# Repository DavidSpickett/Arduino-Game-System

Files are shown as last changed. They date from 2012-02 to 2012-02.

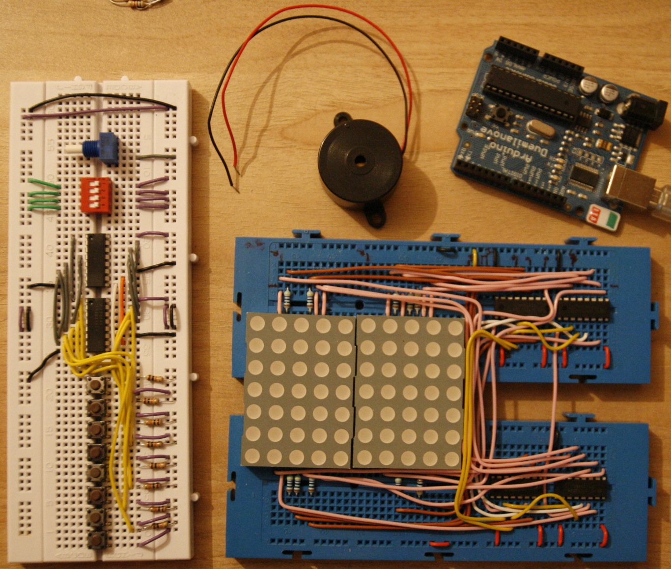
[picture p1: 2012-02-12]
Prototype hardware.JPG

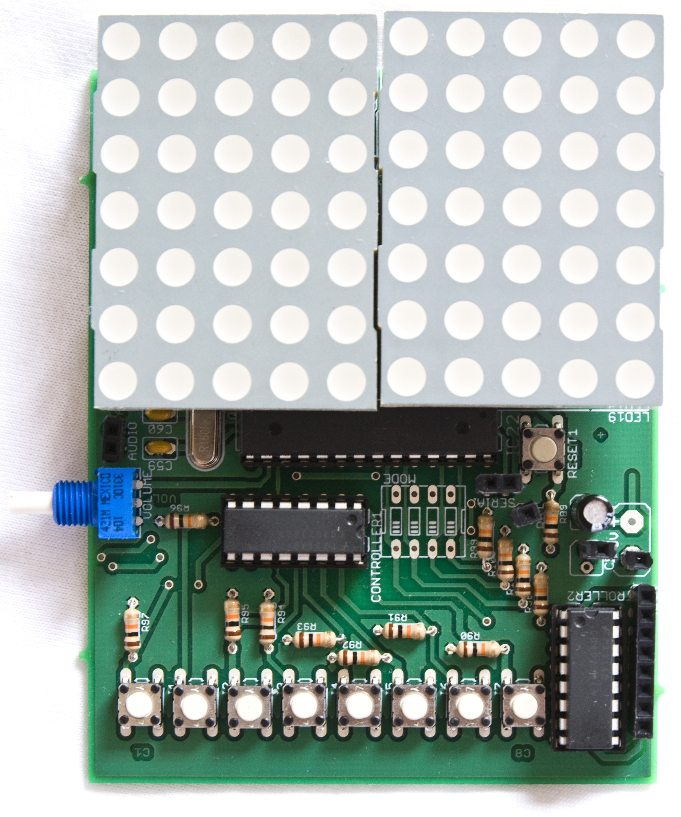
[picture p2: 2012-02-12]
Final board.jpg

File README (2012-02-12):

This is my second year design project. The module was based around the Arduino system and I chose to build a simple hand held game system using L.E.D. grids as displays.

Final report - full documentation of the project
parts.txt - parts list as exported from Eagle
Eagle Files - board layout and schematic created in Eagle
pong_PCB - the final demo application for the device, plays one or two player pong at a set speed.
scoll_text_PCB - a demo which scrolls a long piece of text across the displays.
Final board - a picture of the final assembled device
Final PCB - the final board layout
Final schematic - the final schematic for the system
Programming - the board begin programmed using an empty Arduino
Prototype hardware - the initial hardware for the system
Data Sheets - data sheets for the main components used

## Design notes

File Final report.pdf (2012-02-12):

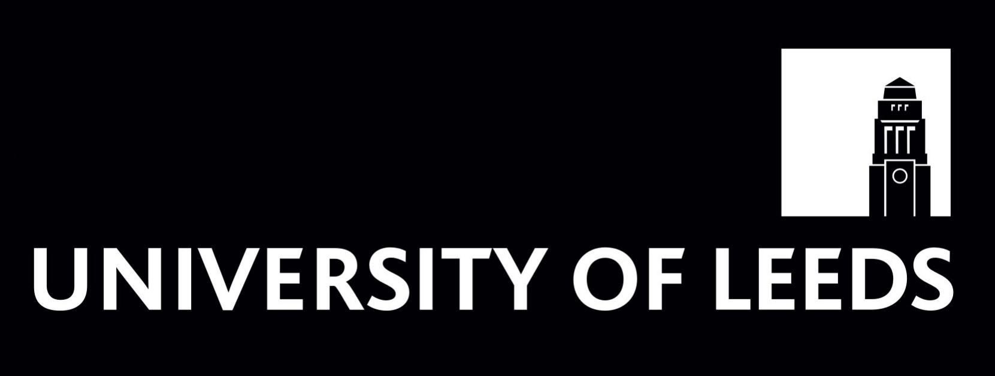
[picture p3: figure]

# Arduino-based games system

# David Spickett

MEng in Electronic and Electrical Engineering

ELEC2645 Embedded Systems Project

## School of Electronic and Electrical Engineering

FACULTY OF ENGINEERING

Session | 2010 / 2011
Student ID | 200483181

Contents

Abstract! | ! | ! | ! | ! | ! | ! | ! | ! | ! | 1
Introduction !! | ! | ! | ! | ! | ! | ! | ! | ! | 1
Software Overview!! | ! | ! | ! | ! | ! | ! | ! | 2
Hardware Overview!! | ! | ! | ! | ! | ! | ! | ! | 4
Testing!! | ! | ! | ! | ! | ! | ! | ! | ! | ! | 8
Conclusion!! | ! | ! | ! | ! | ! | ! | ! | ! | 9
References!! | ! | ! | ! | ! | ! | ! | ! | ! | 9

Arduino-based games system

Abstract

The following document details the design and construction of an Arduino based games system. It includes a display, buttons, external inputs and a speaker connection. It is designed to be reprogrammable and allow users to easily write applications making use of the hardware.

Introduction

The aim of this project was to make a platform to allow users to easily write and quickly iterate Arduino programs that make use of a display. Particularly interactive programs such as games. The system includes and L.E.D. display, input buttons, external inputs and audio output. The final goal is to have the system be much like a development board one might supply to developers prior to the production of a system, abstracting all the hardware access into simple code.

Software Overview

The software for the system is written as a template file which programs are built on. The flowchart below is for a generic program.

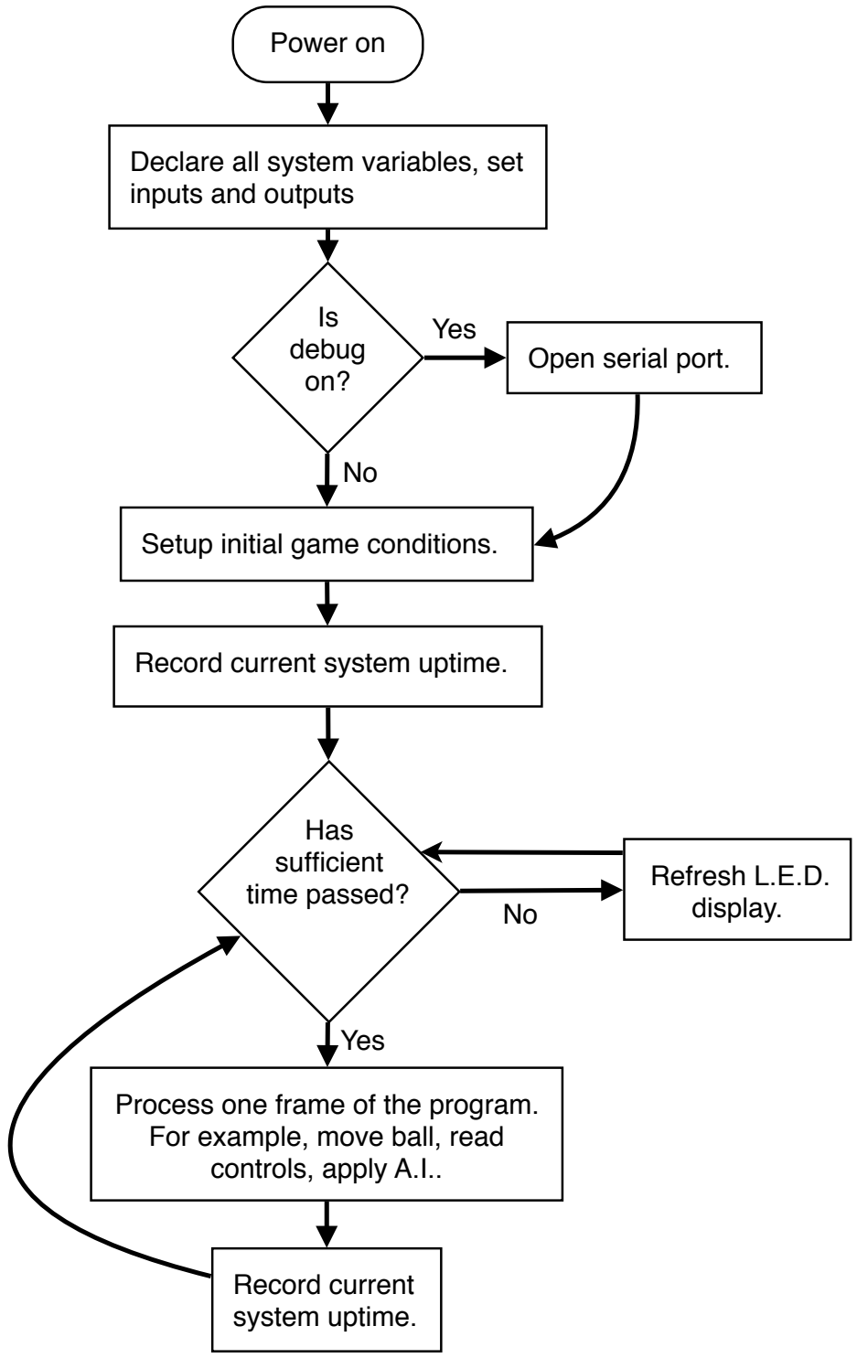
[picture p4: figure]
Power on; Declare all system variables, set inputs and outputs; Is debug; Open serial port.; Yes; Setup initial game conditions.; Record current system uptime.; Has sufficient; time passed?; Refresh L.E.D.; display.; Process one frame of the program. For example, move ball, read controls, apply A.I..

The template has all of the pin numbers built into it by making use of #define statements. For example:
#define speakerPin 10

Using defines reduces program size, makes the built in functions easier to understand and the system configurable.

screenArray -
- a 10x7 array of bytes, which holds all the pixels which make up the screen.
- this is only ever accessed by the system itself.

modeSwitch -
- a byte which holds the current state of the mode switch.
- can be read by calling “readModeSwitch”.

controllerOne & controllerTwo -
- (each one is) a byte which holds the states of the inputs.
- is updated by calling readControllerOne/Two and then queried using readControllerOne/ TwoButton(button).

dataValues -
- this is only ever used by the system and is an array of bytes, each being a power of 2.
- it is used to speed up other system functions by being a lookup table where the code would normally do a calculation.

time -
- an unsigned long which is used to hold the current system uptime in milliseconds.
- this is used to time when the loop of a given program will run, allowing the screen to be refreshed at all other times.

Finally there are functions built in to handle reading and writing to the various pieces of hardware.

setPixel(x,y) -
- turns on the pixel at x,y on the screen.

clearPixel(x,y) -
- as setPixel except the pixel at x,y is turned off.

readPixel(x,y) -
- returns the state of the pixel at x,y.

clearScreen() -
- turns off all pixels.

readControllerOne() -
- reads the built in buttons and store result in controllerOne.

readControllerTwo() -
- as for readControllerOne().

readControllerOneButton(button) -
- reads a given button and returns true if it is held down, false otherwise.

- this makes use of binary logic to do this. The value of the port is anded with the value of the button (in powers of 2), to isolate that bit and if the result is equal to the value of the button then it returns true.

readControllerTwoButton(button) -
- as for readControllerOneButton(button).

playTone(frequency,duration) -
- plays a given frequency for a given time through the speaker output.

updateScreen() -
- this takes the current screenArray and applies it to the actual L.E.D. grids.
- it does this by scanning across both grids simultaneously, setting the same column on each one. Setting a row low turns on the L.E.D. in the current row and column.

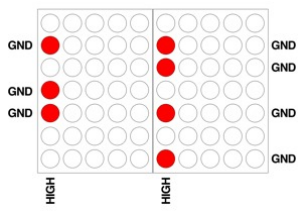
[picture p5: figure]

This function calculates values based on each column of screenArray and outputs these using code based upon the Arduinoʼs built in shiftOut function.

shiftIn(dataPin) -
- this is based on source code from the Arduino shiftIn tutorials, with optmisations for this setup.

readModeSwitch() -
- this reads the value of the mode switch into “modeSwitch”.

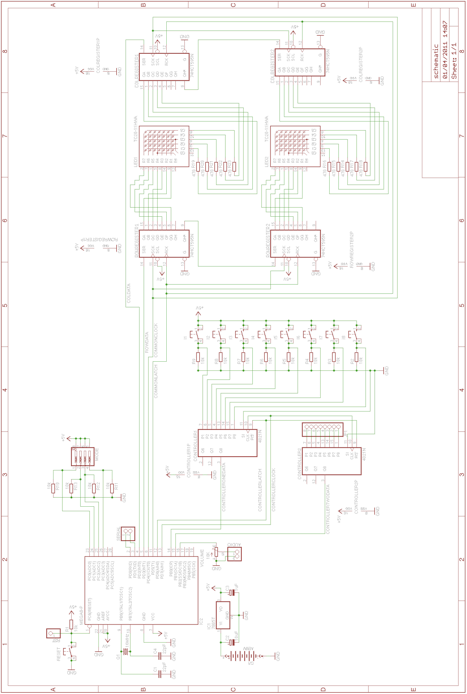
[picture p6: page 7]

Hardware Overview

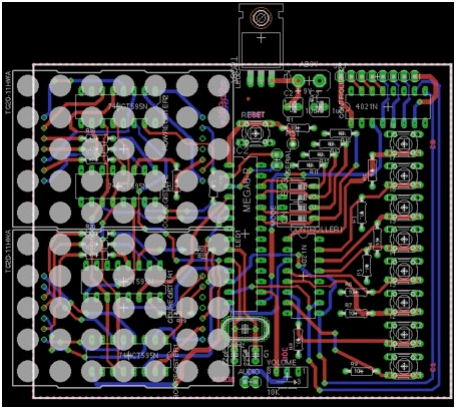
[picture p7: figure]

Part | Value | Device | Package | Library
AUDIO | n/a | PINHD-1X2 | 1X02 | pinhead
C1 | 22pF | C2, 5-3 | C2.5-3 | capacitor-wima
C2 | 10uF | CPOL-EUB45181A | B45181A | resistor
C3 | 1uF | CPOL-EUB45181A | B45181A | resistor
C4 | 22pF | C2, 5-3 | C2.5-3 | capacitor-wima
COLREGISTE R1 | 74HCT595N | 74HCT595N | DIL16 | 74xx-eu
COLREGISTE R2 | 74HCT595N | 74HCT595N | DIL16 | 74xx-eu
CONTROLLER 1 | 4021N | 4021N | DIL16 | 40xx

Part | Value | Device | Package | Library
CONTROLLER 2 | 4021N | 4021N | DIL16 | 40xx
G1 | AB9V | AB9V | AB9V | battery
I1 | n/a | 10-XX | B3F-10XX | switch-omron
I2 | n/a | 10-XX | B3F-10XX | switch-omron
I3 | n/a | 10-XX | B3F-10XX | switch-omron
I4 | n/a | 10-XX | B3F-10XX | switch-omron
I5 | n/a | 10-XX | B3F-10XX | switch-omron
I6 | n/a | 10-XX | B3F-10XX | switch-omron
I7 | n/a | 10-XX | B3F-10XX | switch-omron
I8 | n/a | 10-XX | B3F-10XX | switch-omron
IC1 | 7805T | 7805T | TO220H | linear
IC2 | MEGA8-P | MEGA8-P | DIL28-3 | atmel
JP1 | n/a | PINHD-1X8 | 1X08 | pinhead
LED1 | TC20-11HWA | TC20-11HWA | TC20-11HWA | display-kingbright
LED2 | TC20-11HWA | TC20-11HWA | TC20-11HWA | display-kingbright
MODE | n/a | SW_DIP-4 | EDG-04 | special
Q1 | 16MHz | CRYSTALHC49 U70 | HC49U70 | crystal
R1 | 10k | R-EU_0204/7 | 0204/7 | resistor
R13 | 10k | R-EU_0204/7 | 0204/7 | resistor
R14 | 470 | R-EU_0204/7 | 0204/7 | resistor
R23 | 470 | R-EU_0204/7 | 0204/7 | resistor
RESET | n/a | 10-XX | B3F-10XX | switch-omron
ROWREGISTE R1 | 74HCT595N | 74HCT595N | DIL16 | 74xx-eu

Part | Value | Device | Package | Library
ROWREGISTE R2 | 74HCT595N | 74HCT595N | DIL16 | 74xx-eu
RST | n/a | PINHD-1X1 | 1X01 | pinhead
SERIAL | n/a | PINHD-1X2 | 1X02 | pinhead
VOLUME | 10k | TRIM_EU-S63S | S63S | pot

Most of the components are very basic but I will go into a few particular choices.

L.E.D. grids -
For this project I used 5x7 grids as they were readily available and combining two of them gives a display wider than it is high, which is sometimes advantageous.

Shift Registers -
There is one register for the first gridʼs rows and columns and the secondʼs, for a total of four. Each pair of registers is tied together using the firstʼs serial output. Every time the screen updates the system pushes two bytes to each pair of registers and the first byte overflows to the second. As this operation is synchronised, this means that all the shift clock and latch clocks can be controlled by the same lines. This reduces the outputs needed.

Testing

Hardware -
My final P.C.B. was missing the voltage regulator due to an error in my design. With the voltage regulatorʼs footprint positioned over the edge of the design, it was excluded. This was only a minor set back as I can use an external supply to deliver the voltage needed or possibly make a custom cable that would include a battery clip and regulator in one.
I also confirmed that the micro-controller can be programmed whilst on the board by hooking it up to my own usb Arduino board.

Software -
I wrote a test program for the unit which does the following things:
- display the state of all inputs.
- display the state of the mode switch.
- output a constant tone to the audio port.
- run a display test pattern when certain buttons are held.

This showed that all the input hardware was correct (the mode switch was tested using external inputs as the component was wasted on the first P.C.B.) but that the display orientation was not. Initially the displays were in the wrong order, which I solved by changing the order data is sent, so as to invert and mirror the co-ordinates.

Conclusion

This project has impressed upon me the importance of making software flexible, in my case this has enabled me to correct what would otherwise have been show stopping hardware mistakes. I feel the design fits well onto itʼs current layout but if I were given the chance to improve it I would move the buttons to the sides of the screens, in two groups of four, like a conventional gamepad. Then I could add pull down resistors to the external inputs and possibly a header to the built in buttons to further expand the systemʼs adaptability.
In the future I would like to expand on this design by using a larger, rgb display and a single micro-controller for driving it. This would allow the system to control the colour mix and brightness more accurately whilst separate controller deals with program logic and sends the driver pixel values over serial. Much like a conventional P.C. would with a discrete graphics card.

References

Arduino “wiring_shift.c” source code - http://code.google.com/p/arduino/source/browse/trunk/hardware/arduino/cores/arduino/wiring_shift.c (this was used as the basis for my functions)

Row-Column Scanning to control an 8x8 LED Matrix - http://www.arduino.cc/en/Tutorial/RowColumnScanning (background on the technique, although I did not use their code)

RCP Electronics EagleCad Tutorials - http://youtu.be/qG0O9LKH-_E (a series of videos detailing how to use Eagle)

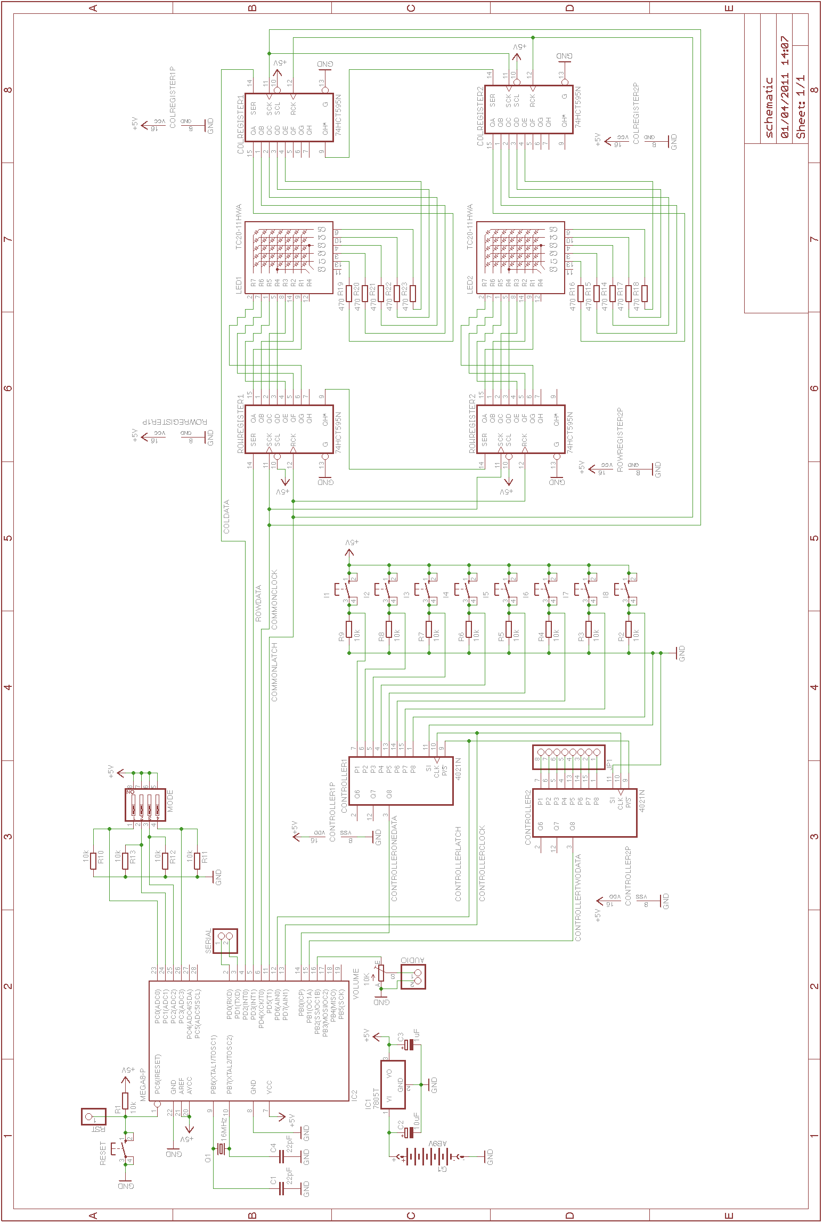
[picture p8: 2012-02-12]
Final schematic.png

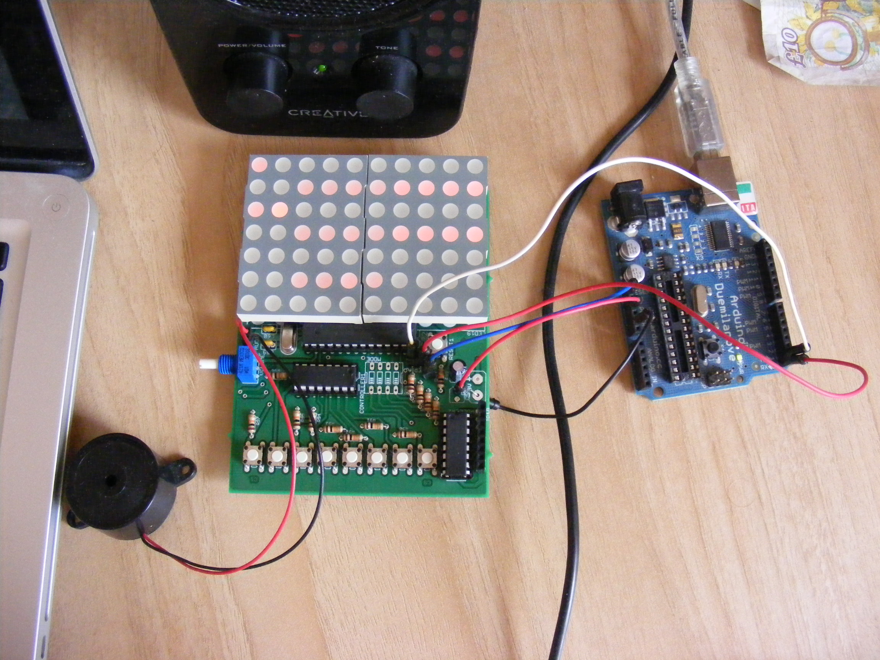
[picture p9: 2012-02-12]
Programming.JPG

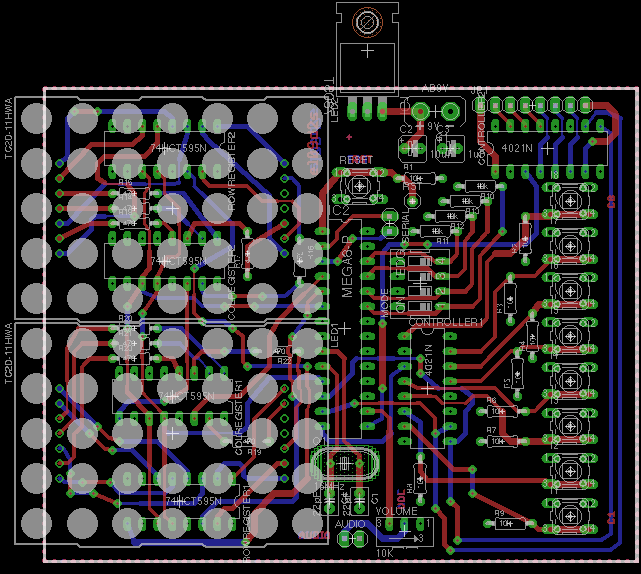
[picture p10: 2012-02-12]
Final PCB.png

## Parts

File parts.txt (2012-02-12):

Partlist

Exported from schematic.sch at 06/04/2011 14:57

EAGLE Version 5.11.0 Copyright (c) 1988-2010 CadSoft

Part         Value          Device         Package    Library            Sheet

AUDIO                       PINHD-1X2      1X02       pinhead            1
C1           22pF           C2,5-3         C2.5-3     capacitor-wima     1
C2           10uF           CPOL-EUB45181A B45181A    resistor           1
C3           1uF            CPOL-EUB45181A B45181A    resistor           1
C4           22pF           C2,5-3         C2.5-3     capacitor-wima     1
COLREGISTER1 74HCT595N      74HCT595N      DIL16      74xx-eu            1
COLREGISTER2 74HCT595N      74HCT595N      DIL16      74xx-eu            1
CONTROLLER1  4021N          4021N          DIL16      40xx               1
CONTROLLER2  4021N          4021N          DIL16      40xx               1
G1           AB9V           AB9V           AB9V       battery            1
I1                          10-XX          B3F-10XX   switch-omron       1
I2                          10-XX          B3F-10XX   switch-omron       1
I3                          10-XX          B3F-10XX   switch-omron       1
I4                          10-XX          B3F-10XX   switch-omron       1
I5                          10-XX          B3F-10XX   switch-omron       1
I6                          10-XX          B3F-10XX   switch-omron       1
I7                          10-XX          B3F-10XX   switch-omron       1
I8                          10-XX          B3F-10XX   switch-omron       1
IC1          7805T          7805T          TO220H     linear             1
IC2          MEGA8-P        MEGA8-P        DIL28-3    atmel              1
JP1                         PINHD-1X8      1X08       pinhead            1
LED1         TC20-11HWA     TC20-11HWA     TA20-11HWA display-kingbright 1
LED2         TC20-11HWA     TC20-11HWA     TA20-11HWA display-kingbright 1
MODE                        SW_DIP-4       EDG-04     special            1
Q1           16MHz          CRYSTALHC49U70 HC49U70    crystal            1
R1           10k            R-EU_0204/7    0204/7     resistor           1
R2           10k            R-EU_0204/7    0204/7     resistor           1
R3           10k            R-EU_0204/7    0204/7     resistor           1
R4           10k            R-EU_0204/7    0204/7     resistor           1
R5           10k            R-EU_0204/7    0204/7     resistor           1
R6           10k            R-EU_0204/7    0204/7     resistor           1
R7           10k            R-EU_0204/7    0204/7     resistor           1
R8           10k            R-EU_0204/7    0204/7     resistor           1
R9           10k            R-EU_0204/7    0204/7     resistor           1
R10          10k            R-EU_0204/7    0204/7     resistor           1
R11          10k            R-EU_0204/7    0204/7     resistor           1
R12          10k            R-EU_0204/7    0204/7     resistor           1
R13          10k            R-EU_0204/7    0204/7     resistor           1
R14          470            R-EU_0204/7    0204/7     resistor           1
R15          470            R-EU_0204/7    0204/7     resistor           1
R16          470            R-EU_0204/7    0204/7     resistor           1
R17          470            R-EU_0204/7    0204/7     resistor           1
R18          470            R-EU_0204/7    0204/7     resistor           1
R19          470            R-EU_0204/7    0204/7     resistor           1
R20          470            R-EU_0204/7    0204/7     resistor           1
R21          470            R-EU_0204/7    0204/7     resistor           1
R22          470            R-EU_0204/7    0204/7     resistor           1
R23          470            R-EU_0204/7    0204/7     resistor           1
RESET                       10-XX          B3F-10XX   switch-omron       1
ROWREGISTER1 74HCT595N      74HCT595N      DIL16      74xx-eu            1
ROWREGISTER2 74HCT595N      74HCT595N      DIL16      74xx-eu            1
RST                         PINHD-1X1      1X01       pinhead            1
SERIAL                      PINHD-1X2      1X02       pinhead            1
VOLUME       10K            TRIM_EU-S63S   S63S       pot                1

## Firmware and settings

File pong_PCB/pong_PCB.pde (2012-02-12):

//Make this TRUE to see debug output on the serial line
#define debug false

///////////// SYSTEM PIN NUMBERS //////////////////////

//GRID CONTROL PINS

//Column serial data in
#define colSerialDataIn 2

//Row serial data in
#define rowSerialDataIn 3

//Common latch clock
#define commonLatchClock 5

//Common shift clock
#define commonShiftClock 4

//CONTROLLER CONTROL PINS

//Controller port clock pin
#define controllerClock 7

//Controller Latch Pin
#define controllerLatch 6

//Controller One Serial Out
#define controllerOneSerialOut 8

//Controller Two Serial Out
#define controllerTwoSerialOut 9

//AUDIO PINS

//Speaker pin
#define speakerPin 10

//MODE SWITCH PINS

#define modeSwitchBitOne 14
#define modeSwitchLength 4

//////////////// SYSTEM VARIABLES ///////////////////////

//MODE SWITCH VARIABLES

byte modeSwitch;

//CONTROLLER VARIABLES

byte controllerOne;
byte controllerTwo;

//SCREEN VARIABLES

//Array to hold all the screen data
byte screenArray[7][10] = {{0,0,0,0,0,0,0,0,0,0},
                           {0,0,0,0,0,0,0,0,0,0},
                           {0,0,0,0,0,0,0,0,0,0},
                           {0,0,0,0,0,0,0,0,0,0},
                           {0,0,0,0,0,0,0,0,0,0},
                           {0,0,0,0,0,0,0,0,0,0},
                           {0,0,0,0,0,0,0,0,0,0}};

//Values used to get the bytes to send to the registers.
//Pre computed for speed
const byte dataValues[8] = {1,2,4,8,16,32,64,128};

/////////// HELPER MACROS /////////////////

//SCREEN MACROS

#define setPixel(x,y) screenArray[y][x]=1
#define clearPixel(x,y) screenArray[y][x]=0
#define readPixel(x,y) screenArray[y][x]
#define clearScreen(); for(byte y=0;y<screenHeight;y++){for (byte x=0;x<screenWidth;x++){screenArray[y][x]=0;}}

//Screen size, for game code use   
#define screenHeight 7
#define screenWidth 10

//CONTROLLER MACROS

#define readControllerOne() controllerOne=shiftIn(controllerOneSerialOut)
#define readControllerTwo() controllerTwo=shiftIn(controllerTwoSerialOut)
#define readControllerOneButton(x) ((controllerOne&(1<<(x-1)))==(1<<(x-1)))
#define readControllerTwoButton(x) ((controllerTwo&(1<<(x-1)))==(1<<(x-1)))

//SPEAKER MACROS

#define playTone(x,y) tone(speakerPin,x,y)

////////// GAME VARIABLES /////////////////

byte playerOneY;
byte playerTwoY;

byte playerOneScore = 0;
byte playerTwoScore = 0;

byte ballX;
byte ballY;

int ballXV;
int ballYV;

#define aiDelayRs 31
byte aiDelay = aiDelayRs;

#define ballDelayRs 30
byte ballDelay = ballDelayRs;

#define playerOnePaddleSize 2
#define playerTwoPaddleSize 2

int controlOption = 0;

unsigned long time;

void setup() {

  if (debug) {
    
    //Open serial port
    Serial.begin(9600);
  }

  //Setup outputs
  pinMode(commonLatchClock, OUTPUT);
  pinMode(commonShiftClock, OUTPUT);
  pinMode(rowSerialDataIn, OUTPUT);
  pinMode(colSerialDataIn, OUTPUT);

  pinMode(controllerClock,OUTPUT);
  pinMode(controllerLatch, OUTPUT);
  pinMode(controllerOneSerialOut, INPUT);
  pinMode(controllerTwoSerialOut, INPUT);
  
  for (byte i = 0; i<modeSwitchLength; i++) {
   
   pinMode(modeSwitchBitOne+i,INPUT); 
  }

  pinMode(speakerPin, OUTPUT);

  time = millis();
  
  resetGame();
  
  readControllerOne();
  
  if (readControllerOneButton(1)) {
   
   controlOption = 1; //Control left side 
  } else if (readControllerOneButton(2)) {
   
   controlOption = 2; //Control right side 
  } else if (readControllerOneButton(3)) {
   
   controlOption = 3; //Control both 
  }
}

void loop() {
  
  //This limits the frame rate of your program
  //It will do one iteration every XmS
  readModeSwitch();
  
  if ((millis()-time) >= modeSwitch) { 
   
   doPong();
   time = millis();
  }

  updateScreen();
}

void testScreen() {
 
 clearScreen();
 
 unsigned long testTime = millis();
 boolean cont = true;
 byte i = 0;
 byte j = 0;
 
 setPixel(i,j);
 
 while (cont) {
   
   if ((millis()-testTime) > 40) {
     
     if (i != (screenWidth-1)) {
      
      playTone(i*100,10);
      i++; 
     } else {
      
      i = 0;
      j++; 
     }
     
     setPixel(i,j);
     
     if (j > (screenHeight-1)) {
      cont = false; 
     }
     
     testTime = millis();
   }
   
   updateScreen();
 }
 
 clearScreen();
}

void resetGame() {

  //Seed randomness
  randomSeed(analogRead(0));

  //Initial setup
  if (random(2) == 1) {

    ballXV = -1;
    ballX = 7;
  } 
  else {

    ballXV = 1;
    ballX = 2;
  }

  randomSeed(analogRead(0));

  if (random(2) == 1) {

    ballYV = 1;
  } 
  else {

    ballYV = -1;
  }

  ballY = 3;

  playerOneY = 3-((playerOnePaddleSize/2)-1); //The minus 1 takes care of the case 
  playerTwoY = 3-((playerTwoPaddleSize/2)-1); //where the size is six and it would draw over the scores.
}

void doPong() {
  
  //Clear the screenArray
    for (int i = 0; i<screenWidth; i++) {
      for (int j = 0; j<screenHeight; j++) {

        clearPixel(i,j);
      }
    }

    byte oldPlayerOneY = playerOneY;
    byte oldPlayerTwoY = playerTwoY;

    //Apply movement to paddles

    if (aiDelay == 0) {
      
      if ((ballXV == -1) && (controlOption != 1) && (controlOption != 3)) {
        
        //Player One
        if ((ballY > (playerOneY+1)) && (playerOneY != (screenHeight-playerOnePaddleSize))) {

          playerOneY++; 
        }

        if ((ballY < playerOneY) && (playerOneY != 1)) {

          playerOneY--;
        }
      }

      if ((ballXV == 1) && (controlOption != 2) && (controlOption != 3)) {
        
        //Player Two
        if ((ballY > (playerTwoY+1)) && (playerTwoY != (screenHeight-playerTwoPaddleSize))) {

          playerTwoY++; 
        }

        if ((ballY < playerTwoY) && (playerTwoY != 1)) {

          playerTwoY--;
        } 
      }
      
      readControllerOne();
      
      //Controls for the player
      if (controlOption == 1) {
        
        //Move left paddle
        if (readControllerOneButton(1) && (playerOneY != 1)) {
         
         playerOneY--; 
        }
        
        if (readControllerOneButton(8) && (playerOneY != (screenHeight-playerOnePaddleSize))) {
          
          playerOneY++;
        }
        
      } else if (controlOption == 2) {
        
        //Move right paddle
        if (readControllerOneButton(1) && (playerTwoY != 1)) {
         
         playerTwoY--; 
        }
        
        if (readControllerOneButton(8) && (playerTwoY != (screenHeight-playerTwoPaddleSize))) {
          
          playerTwoY++;
        }
        
      } else if (controlOption == 3) {
        
        //Control both paddles
        
        //Move left paddle
        if (readControllerOneButton(1) && (playerOneY != 1)) {
         
         playerOneY--; 
        }
        
        if (readControllerOneButton(3) && (playerOneY != (screenHeight-playerOnePaddleSize))) {
          
          playerOneY++;
        }
        
        //Move right paddle
        if (readControllerOneButton(6) && (playerTwoY != 1)) {
         
         playerTwoY--; 
        }
        
        if (readControllerOneButton(8) && (playerTwoY != (screenHeight-playerTwoPaddleSize))) {
          
          playerTwoY++;
        }
      }

      aiDelay = aiDelayRs;
    }

    aiDelay--;

    //Draw paddles
    for (int i = 0; i<playerOnePaddleSize; i++) {
      
      setPixel(0,playerOneY+i);
    }
    
    for (int i = 0; i<playerTwoPaddleSize; i++) {
      
      setPixel(screenWidth-1,playerTwoY+i);
    }

    if (ballDelay == 0) {

      if ((ballX == 0) || (ballX == (screenWidth-1))) {
        
        boolean gameOver = false;

        //Ball hit side
        if (ballX == 0) {

          //Left side
          if (playerTwoScore != 5) {

            playerTwoScore++;
          } 
          else {

            playerOneScore = 0;
            playerTwoScore = 0;
            
            gameOver = true;
            
            testScreen();
          }
        }

        //Right side
        if (ballX == (screenWidth-1)) {

          if (playerOneScore != 5) {

            playerOneScore++;
          } 
          else {

            playerOneScore = 0;
            playerTwoScore = 0;
            
            gameOver = true;
            
            testScreen();
          }
        }
        
        if (gameOver) {
          
          noTone(speakerPin);
          playTone(500, 500);
        } else {
          
          noTone(speakerPin);
          playTone(2000, 300);
        }
        
        resetGame();
      }

      if (((ballX == 1) && (((ballY >= oldPlayerOneY) && (ballY <= (oldPlayerOneY+(playerOnePaddleSize-1)))) || (((oldPlayerOneY+playerOnePaddleSize) == ballY) && (ballYV == -1)) || (((oldPlayerOneY-1) == ballY) && (ballYV == 1)))) 
        || ((ballX == (screenWidth-2)) && (((ballY >= oldPlayerTwoY) && (ballY <= (oldPlayerTwoY+(playerTwoPaddleSize-1)))) || (((oldPlayerTwoY+playerTwoPaddleSize) == ballY) && (ballYV == -1)) || (((oldPlayerTwoY-1) == ballY) && (ballYV == 1))))) { 

        ballXV *= -1;
        noTone(speakerPin);
        playTone(1000,100);
      }
      
      //(oldPlayerOneY == ballY) || ((oldPlayerOneY+1) == ballY)

      //Apply movement to ball
      if ((ballY == 1) || (ballY == (screenHeight-1)) || ((ballX == 1) && (((ballY == (playerOneY+playerOnePaddleSize)) && (ballYV == -1)) || ((ballY == (playerOneY-1)) && (ballYV == 1))))
         || ((ballX == (screenWidth-2)) && (((ballY == (playerTwoY+playerTwoPaddleSize)) && (ballYV == -1)) || ((ballY == (playerTwoY-1)) && (ballYV == 1))))) {

        ballYV *= -1;
        noTone(speakerPin);
        playTone(1000,100);
      }

      if ((((ballX + ballXV) >=  0)) && ((ballX + ballXV) <= (screenWidth-1))) {
        
        ballX += ballXV;
      }
      
      if (((ballY + ballYV) > 0) && ((ballY + ballYV) <= (screenHeight-1))) {
        
        ballY += ballYV;
      }

      ballDelay = ballDelayRs;
    }

    ballDelay--;

    //Draw the ball
    setPixel(ballX,ballY);

    //Draw on scores
    for (int i = 0; i<playerOneScore; i++) {

      setPixel(i,0);
    }

    for (int i = 0; i<playerTwoScore; i++) {

      setPixel(screenWidth-i-1,0); 
    }
}

void updateScreen() {

  //This function uses the data in screenArray to setup the registers

  //This main for loop iterates over the 5 pairs of columns
  for (byte i = 0; i<5; i++) {

    //Calculate the bytes we need to shift out

    //Rows
    //Setting a row LOW will turn it on
    //These are done in reverse order because the first will be shifted over
    //to the second register once the second byte is sent.

    //Byte 2, second grid rows
    byte rowValueTwo = 0;

    //Byte 1, first grid rows 
    byte rowValueOne = 0;

    //Iterate over the rows to make up the value
    for (byte j = 0; j<screenHeight; j++) {

      //Second set of rows
      if (screenArray[j][i] == 0) {

        //This means the row is meant to be off, so we want to set it HIGH
        rowValueTwo += dataValues[6-j];
      }

      //First set of rows
      if (screenArray[j][i+5] == 0) {

        //Set that row HIGH
        rowValueOne += dataValues[6-j];
      }
    } //END row for loop

    
    if (debug) {
     
     Serial.print("Rows one value: ");
     Serial.println(rowValueOne);
     Serial.print("Rows two value: ");
     Serial.println(rowValueTwo);
    }
     
    //Columns
    //Setting a column HIGH will turn it on
    //We already know what sequence we want to use so we can just grab a value based 
    //on where we are in the refresh.
    
    if (debug) {
     
     Serial.print("Column value: ");
     Serial.println(dataValues[i],BIN);
     Serial.println(""); 
    }
     
    //Now we can do the actual sending of the data

    //Set the common latch pin low to allow data to be shifted in
    digitalWrite(commonLatchClock, LOW);

    //First column byte and first row byte
    for (byte j = 0; j < 8; j++)  {

      digitalWrite(colSerialDataIn, !!(dataValues[4-i] & (1 << (7 - j))));
      digitalWrite(rowSerialDataIn, !!(rowValueOne & (1 << (7-j))));

      digitalWrite(commonShiftClock, HIGH);
      digitalWrite(commonShiftClock, LOW);
    }
    
    //Second column byte and second row byte
    //Taken from the shiftOut() source code. (using MSBF)
    for (byte j = 0; j < 8; j++)  {

      digitalWrite(colSerialDataIn, !!(dataValues[4-i] & (1 << (7 - j))));
      digitalWrite(rowSerialDataIn, !!(rowValueTwo & (1 << (7 - j))));

      digitalWrite(commonShiftClock, HIGH);
      digitalWrite(commonShiftClock, LOW);
    }

    //Set latch clock HIGH to tell the registers sending has ended
    digitalWrite(commonLatchClock,HIGH);

  } // END column for loop
}  

byte shiftIn(byte dataPin) { 

  byte pinState;
  byte dataIn = 0;

  digitalWrite(controllerLatch, HIGH);
  delayMicroseconds(20);
  digitalWrite(controllerLatch, LOW);

  for (byte i = 0; i <= 7; i++) {

    //Set low to tigger the next bit to be put onto the serial line
    digitalWrite(controllerClock, LOW);
    //delayMicroseconds(0.2); //This delay appears to not be needed

    if (digitalRead(dataPin)) {

      //set the bit to 0 no matter what
      dataIn |= dataValues[(7-i)];
    }

    //Set clock HIGH so we can read the next bit the next time the loop comes around
    digitalWrite(controllerClock, HIGH);
  }

  if (debug) {

    if (dataPin == controllerOneSerialOut) {

      Serial.print("Controller One: ");
    } 
    else if (dataPin == controllerTwoSerialOut) {

      Serial.print("Controller Two: ");
    }

    Serial.println(dataIn,BIN);
  }

  return dataIn;
}

void readModeSwitch() {
  
 modeSwitch = 0;
 
 for (byte i = 0; i<modeSwitchLength; i++) {
  
  if (digitalRead(modeSwitchBitOne+i)) {
   
   modeSwitch += (1 << i);
  }
 }

 if (debug) {
  
  Serial.print("Mode Switch: ");
  Serial.println(modeSwitch,BIN);
 } 
}
